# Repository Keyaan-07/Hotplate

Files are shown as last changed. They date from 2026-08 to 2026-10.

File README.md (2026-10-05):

# Hotplate
An open-source hotplate designed to take power from USB type-C and then be configured and controlled over Wi-Fi. It uses the ESP32-C3 microcontroller, along with 16MB of storage. There are two terminal blocks to connect with the heating element and it's temperature sensor. There is short circuit protection along with accurate current measurement on the power lines. The control frequency is 10KHz for the heating element. The heating element can be mounted on standoffs so as to not heat the surface below it. 

Check out the Project's files on KiCanvas([PCB](https://github.com/Keyaan-07/Hotplate/tree/main/hardware) and [Heating element](https://github.com/Keyaan-07/Hotplate/tree/main/hardware)) and [Onshape](https://cad.onshape.com/documents/19aaa7739f645838b4ad0ae7/w/c026fb920f31f6c5ff4ae7d0/e/9c380aaf866f8abdd3d2d5e3)!

Features:  
- Upto 45W heating
- Wi-Fi Controlled
- Overcurrent protection & shortcircuit protection. 
- accurate current measurement
- Integrated temperature sensor
- Open Source!
- integrated ADC for NTC temperature readings
  
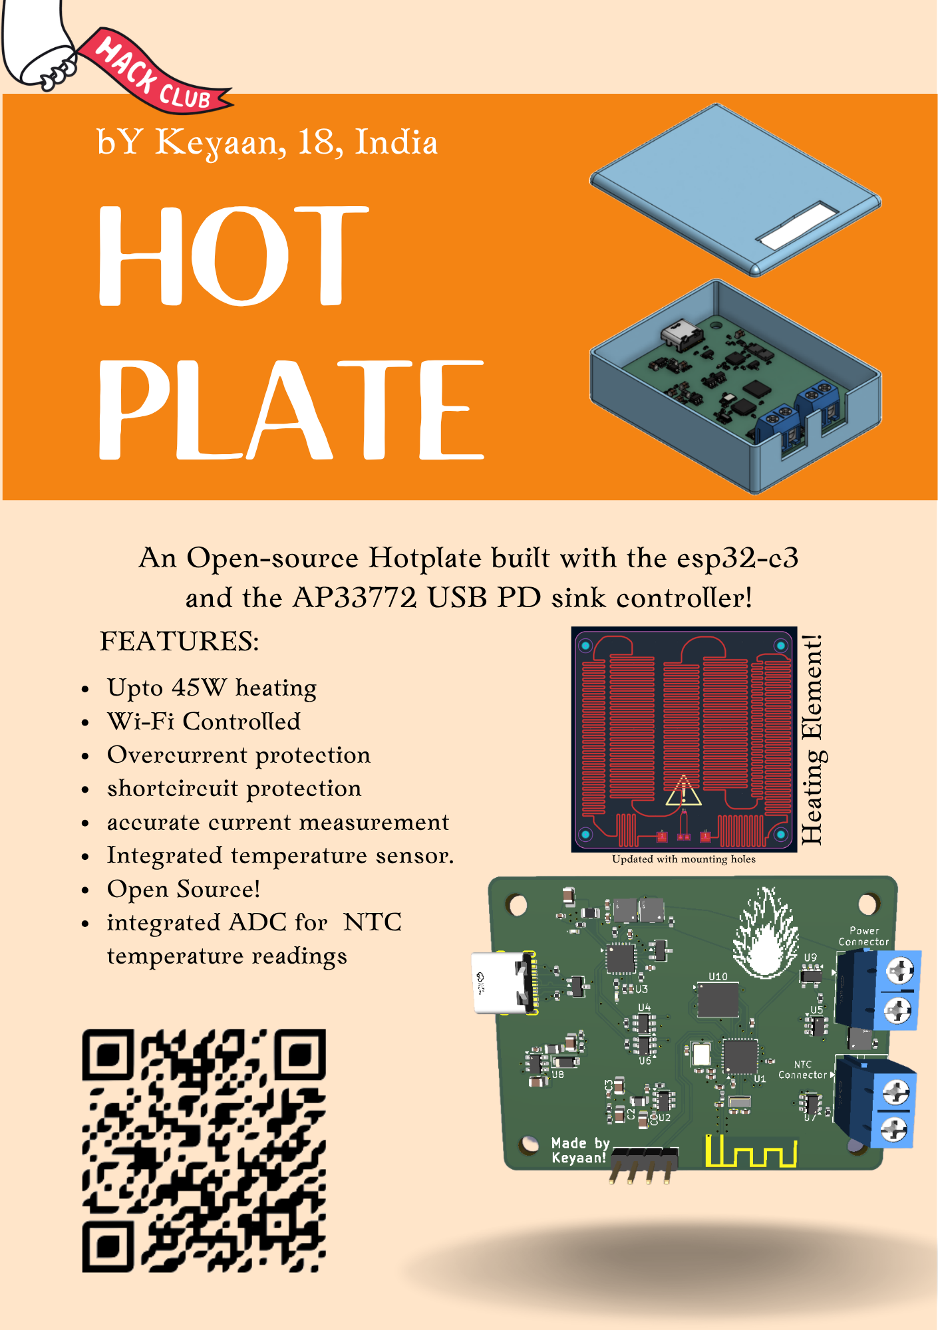
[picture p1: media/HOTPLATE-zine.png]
zine

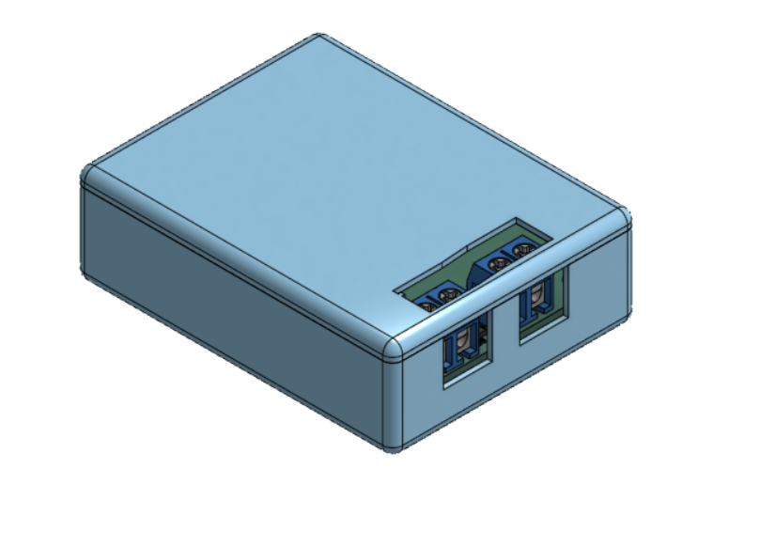
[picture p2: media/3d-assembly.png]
enclosure
  
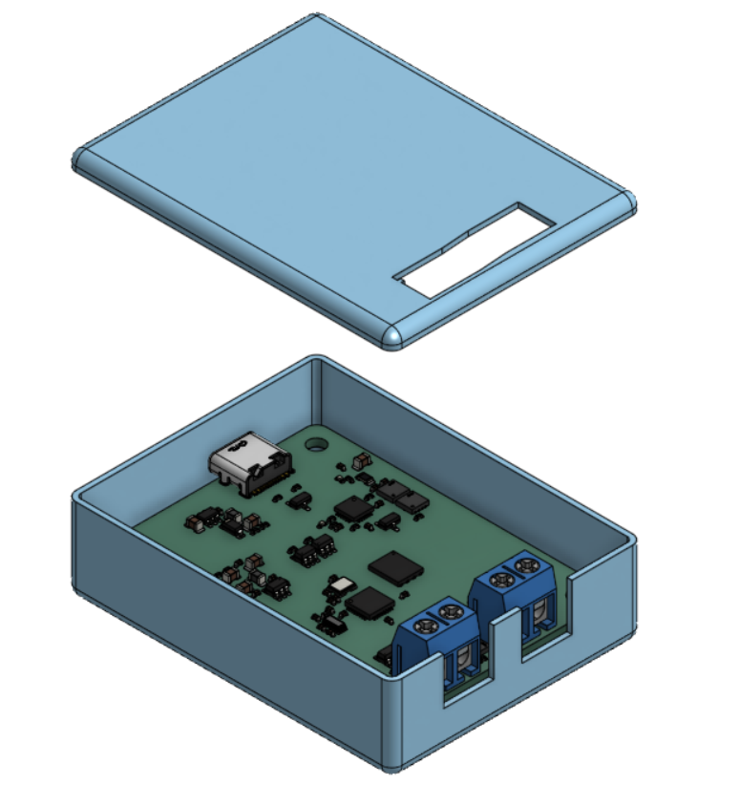
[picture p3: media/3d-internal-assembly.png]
internal parts
  
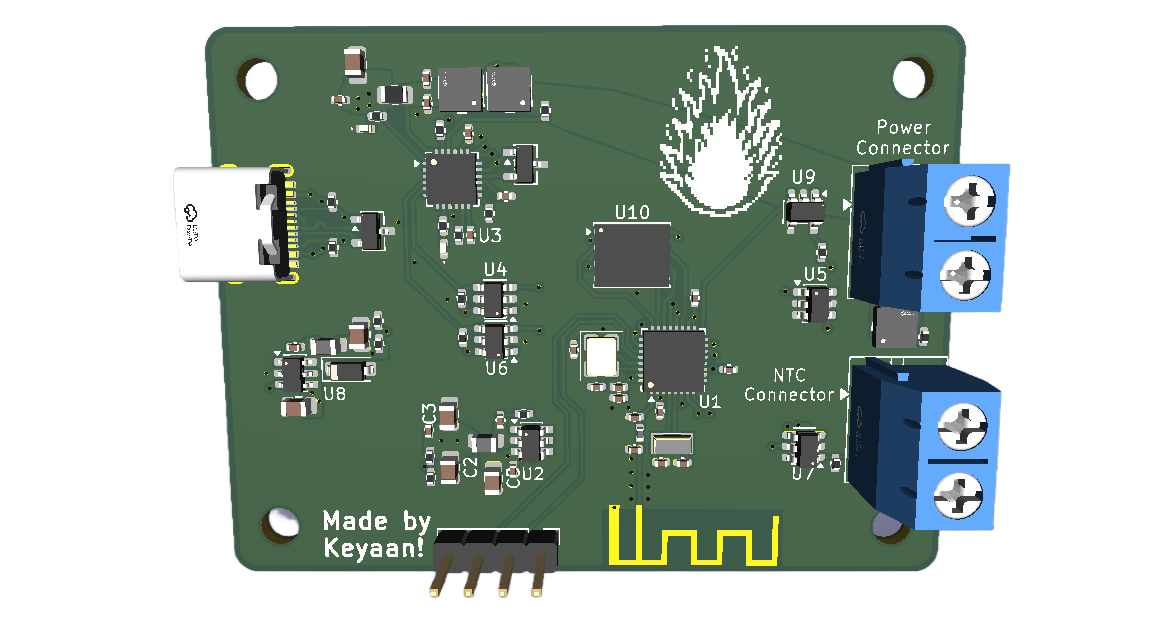
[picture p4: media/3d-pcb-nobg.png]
3d-pcb
  
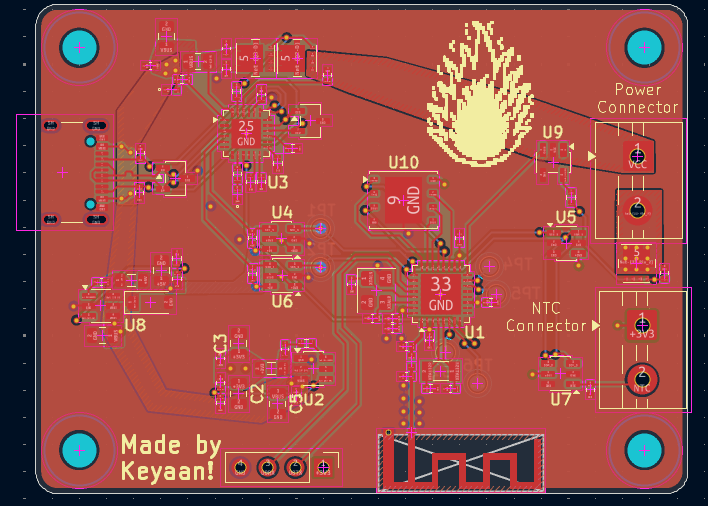
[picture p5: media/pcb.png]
pcb
  
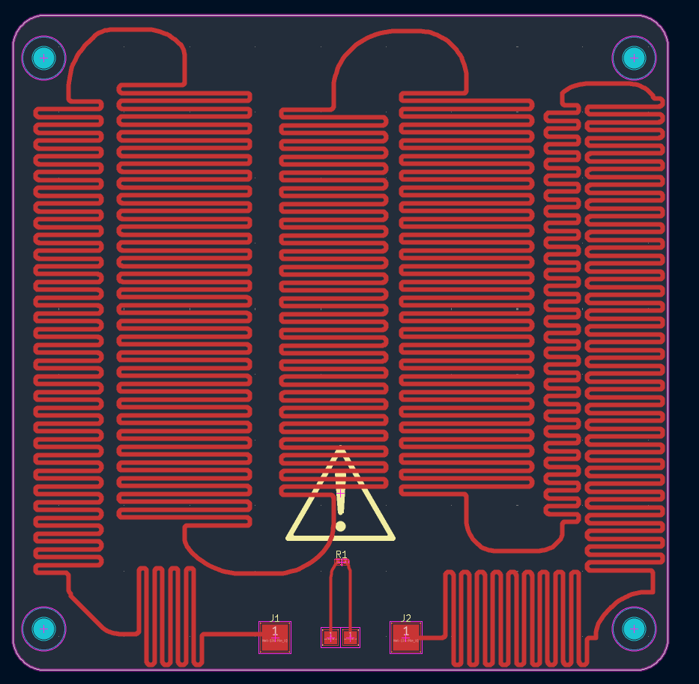
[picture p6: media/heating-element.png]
heating element
  
schematic  

wiring diagram between two parts:   
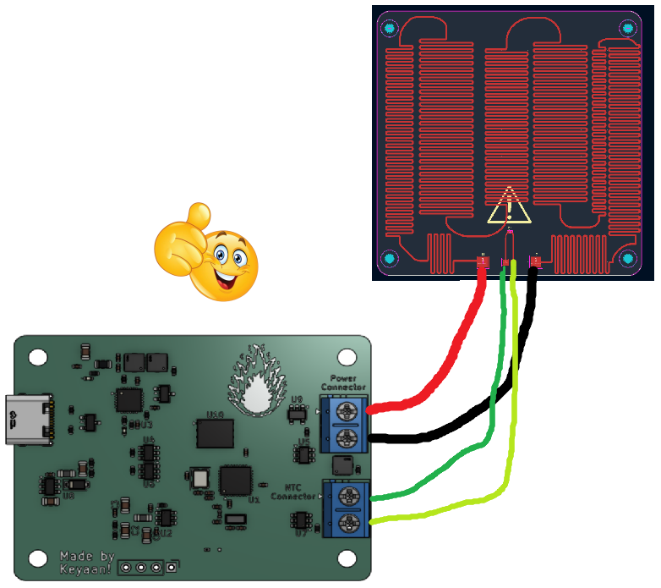
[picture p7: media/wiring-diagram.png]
wiring diagram
  
##### (made by yours truly in paint)

### Why i made this project
I really wanted to build a custom hotplate so that i could make my own PCBs with ease and not struggle!
The heating element is made up of an aluminium PCB so that there is good thermal conductivity.

### Assembly instructions
1. Upload the gerber files from the [production](/hardware/production/) folder to your specific PCB fab. 
2. Order PCBs and a stencil for soldering. 
3. Order all the parts from the links in the [bom.csv](/bom.csv) file. 
4. Get some solder paste and paste it onto the PCB. pick and place all the components. 
5. heat the PCB in an oven/a reflow station. 
6. connect all the THT components
7. flash the firmware via a USB to UART converter. 
8. connect the heating element. You are done!

### Note about firmware
I dont think i will be able to do the firmware unless and until i have the project in hand, because this requires proper PID tuning to just get the temperature right, and also it needs to be adjusted for errors in temperature measurement and power control!

# BOM
|Sr. No.|Designator |Function |Value |Footprint |Quantity|Price |Amount |Link |
|---|---|---|---|---|---|---|---|---|
|1 |PCB+Stencil |PCB+Stencil |PCB+Stencil |PCB+Stencil |5+1 |7+3.07 |10.07  |https://jlcpcb.com/ |
|2 |Aluminium PCB |Heating element | | |5 |0.8 |4 |https://jlcpcb.com/ |
|2 |C1, C14, C15, C16, C17, C20, C21, C22, C23, C4, C6, C7|capacitors |100n |402 |100 |0.0064 |0.64 |https://www.lcsc.com/product-detail/C100072.html  |
|3 |C10, C11, C8, C9 |capacitors |15p |402 |100 |0.0102 |1.02 |https://www.lcsc.com/product-detail/C326803.html  |
|4 |C12 |capacitors |1.8p |402 |100 |0.0081 |0.81 |https://www.lcsc.com/product-detail/C327209.html  |
|5 |C13 |capacitors |1.2p |402 |100 |0.0055 |0.55 |https://www.lcsc.com/product-detail/C327292.html  |
|6 |C18, C19, C24 |capacitors |1u |402 |50 |0.0162 |0.81 |https://www.lcsc.com/product-detail/C52923.html |
|7 |C2, C25, C26, C27, C3, C5 |capacitors |10u |805 |20 |0.1007 |2.014  |https://www.lcsc.com/product-detail/C15850.html |
|8 |D1, D2 |LED |LED |402 |50 |0.0084 |0.42 |https://www.lcsc.com/product-detail/C25503345.html|
|9 |D3, D4 |ESD protection diodes|ESDA5V3L |SOT-23-3 |5 |0.1017 |0.5085 |https://www.lcsc.com/product-detail/C87911.html |
|10 |D5 |buck diode |1N4148W |D_SOD-123 |50 |0.0084 |0.42 |https://www.lcsc.com/product-detail/C917030.html  |
|11 |J1 |USB connector |USB_C_Receptacle_USB2.0_16P|USB_C_Receptacle_XKB_U262-16XN-4BVC11 |10 |0.062 |0.62 |https://www.lcsc.com/product-detail/C393939.html  |
|12 |J2, J3 |Screw terminals |Screw_Terminal_01x02 |TerminalBlock_MaiXu_MX126-5.0-02P_1x02_P5.00mm|5 |0.102 |0.51 |https://www.lcsc.com/product-detail/C474881.html  |
|13 |J4 | |Conn_01x04_Pin |PinHeader_1x04_P2.54mm_Vertical |5 |0.0319 |0.1595 |https://www.lcsc.com/product-detail/C32713270.html|
|14 |L1, L2 | |4.7u |805 |5 |0.1004 |0.502  |https://www.lcsc.com/product-detail/C17701166.html|
|15 |L3 | |3n |402 |20 |0.0042 |0.084  |https://www.lcsc.com/product-detail/C142230.html  |
|16 |Q1, Q2, Q3 | |AON7262E |DFN-5-1EP_3x3mm_P0.65mm_AON7262E |3 |0.65 |1.95 |https://www.lcsc.com/product-detail/C176755.html  |
|17 |R1 | |30 |402 |100 |0.0006 |0.06 |https://www.lcsc.com/product-detail/C54920779.html|
|18 |R10, R14, R15, R9 | |5.1k |402 |100 |0.0054 |0.54 |https://www.lcsc.com/product-detail/C105872.html  |
|19 |R11 | |1k |402 |100 |0.0041 |0.41 |https://www.lcsc.com/product-detail/C106235.html  |
|20 |R12, R13 | |100k |402 |100 |0.0044 |0.44 |https://www.lcsc.com/product-detail/C60491.html |
|21 |R16, R18, R3, R6, TH1 | |10k |402 |100 |0.0038 |0.38 |https://www.lcsc.com/product-detail/C60490.html |
|22 |R17 | |31.6k |402 |100 |0.0021 |0.21 |https://www.lcsc.com/product-detail/C2998091.html |
|23 |R2 | |56k |402 |100 |0.0018 |0.18 |https://www.lcsc.com/product-detail/C2906875.html |
|24 |R4, R7, R8 | |100 |402 |100 |0.0044 |0.44 |https://www.lcsc.com/product-detail/C106232.html  |
|25 |R5 | |5m |805 |10 |0.0514 |0.514  |https://www.lcsc.com/product-detail/C22450690.html|
|26 |U1 | |ESP32-C3 |QFN-32-1EP_5x5mm_P0.5mm_EP3.7x3.7mm |1 |1.85 |1.85 |https://www.lcsc.com/product-detail/C2838500.html |
|27 |U10 | |W25Q128JVP |WSON-8-1EP_6x5mm_P1.27mm_EP3.4x4.3mm |1 |3.47 |3.47 |https://www.lcsc.com/product-detail/C190862.html  |
|28 |U2 | |TPS56339DDC |SOT-23-6 |1 |0.37 |0.37 |https://www.lcsc.com/product-detail/C2071106.html |
|29 |U3 | |AP33772SDKZ-xx-FA02 |QFN-24-1EP_4x4mm_P0.5mm_EP2.7x2.7mm |1 |2.69 |2.69 |https://www.lcsc.com/product-detail/C5244513.html |
|30 |U4, U6 | |TXS0101DBV |SOT-23-6 |2 |0.585 |1.17 |https://www.lcsc.com/product-detail/C132604.html  |
|31 |U5 | |TMP100 |SOT-23-6 |1 |1.02 |1.02 |https://www.lcsc.com/product-detail/C31810.html |
|32 |U7 | |ADS1110 |SOT-23-6 |1 |1.5 |1.5 |https://www.lcsc.com/product-detail/C16598.html |
|33 |U8 | |LM2842Y |TSOT-23-6 |5 |0.2226 |1.113  |https://www.lcsc.com/product-detail/C30170092.html|
|34 |U9 | |MCP1416 |SOT-23-5 |1 |0.52 |0.52 |https://www.lcsc.com/product-detail/C83775.html |
|35 |Y1 | |40MHz |Crystal_SMD_3225-4Pin_3.2x2.5mm |5 |0.0681 |0.3405 |https://www.lcsc.com/product-detail/C5261245.html |
|36 |Y2 | |32.786KHz |Crystal_SMD_3215-2Pin_3.2x1.5mm |5 |0.19 |0.95 |https://www.lcsc.com/product-detail/C46604081.html|
| | | | | | |Total |43.2555| |
| | | | | | |Parts shipping|11 | |
| | | | | | |JLC shipping  |16.7 | |
| | | | | | |total |70.9555| |

# License
Licensed under the MIT license.

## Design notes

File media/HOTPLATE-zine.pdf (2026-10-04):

# HOT

## bY Keyaan, 18, India

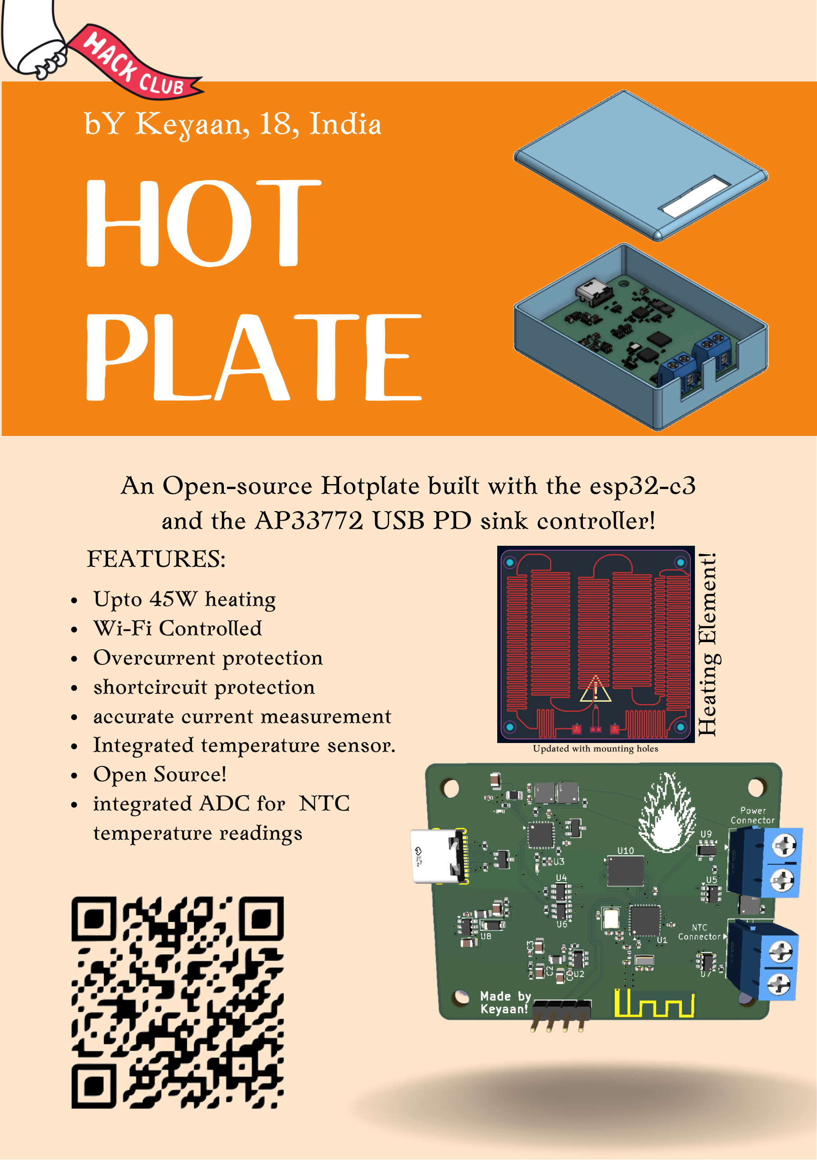
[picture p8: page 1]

# PLATE

### An Open-source Hotplate built with the esp32-c3 and the AP33772 USB PD sink controller!

Upto 45W heating
Wi-Fi Controlled
Overcurrent protection
shortcircuit protection
accurate current measurement Integrated temperature sensor. Open Source!
integrated ADC for NTC
temperature readings

FEATURES:

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
Updated with mounting holes

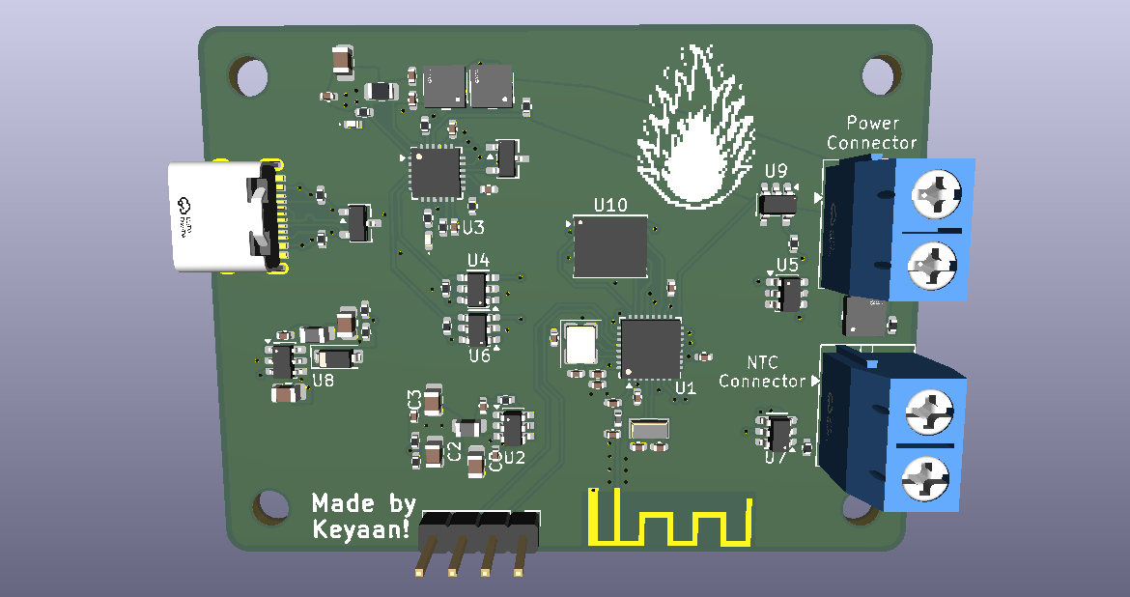
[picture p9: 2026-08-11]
media/3d-pcb.png

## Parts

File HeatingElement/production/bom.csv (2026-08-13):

Designator | Footprint | Quantity | Value | LCSC Part #
J1, J2 | TestPoint_Pad_4.0x4.0mm | 2 | Conn_01x01_Pin
J3, J4 | TestPoint_Pad_2.0x2.0mm | 2 | Conn_01x01_Pin
R1 | 0402 | 1 | NTC

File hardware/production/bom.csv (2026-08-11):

Designator | Footprint | Quantity | Value | LCSC Part #
AE1 | Texas_SWRA117D_2.4GHz_Left | 1 | Antenna_Shield
C1, C14, C15, C16, C17, C20, C21, C22, C23, C4, C6, C7 | 0402 | 12 | 100n
C10, C11, C8, C9 | 0402 | 4 | 15p
C12 | 0402 | 1 | 1.8p
C13 | 0402 | 1 | 1.2p
C18, C19, C24 | 0402 | 3 | 1u
C2, C25, C26, C27, C3, C5 | 0805 | 6 | 10u
D1, D2 | 0402 | 2 | LED
D3, D4 | SOT-23-3 | 2 | ESDA5V3L
D5 | D_SOD-123 | 1 | 1N4148W
J1 | USB_C_Receptacle_XKB_U262-16XN-4BVC11 | 1 | USB_C_Receptacle_USB2.0_16P
J2, J3 | TerminalBlock_MaiXu_MX126-5.0-02P_1x02_P5.00mm | 2 | Screw_Terminal_01x02
J4 | PinHeader_1x04_P2.54mm_Vertical | 1 | Conn_01x04_Pin
L1, L2 | 0805 | 2 | 4.7u
L3 | 0402 | 1 | 3n
Q1, Q2, Q3 | DFN-5-1EP_3x3mm_P0.65mm_AON7262E | 3 | AON7262E
R1 | 0402 | 1 | 30
R10, R14, R15, R9 | 0402 | 4 | 5.1k
R11 | 0402 | 1 | 1k
R12, R13 | 0402 | 2 | 100k
R16, R18, R3, R6, TH1 | 0402 | 5 | 10k
R17 | 0402 | 1 | 31.6k
R2 | 0402 | 1 | 56k
R4, R7, R8 | 0402 | 3 | 100
R5 | 0805 | 1 | 5m
TP1, TP2, TP3, TP4, TP5, TP6 | TestPoint_Pad_D1.5mm | 6 | TestPoint
U1 | QFN-32-1EP_5x5mm_P0.5mm_EP3.7x3.7mm | 1 | ESP32-C3
U10 | WSON-8-1EP_6x5mm_P1.27mm_EP3.4x4.3mm | 1 | W25Q128JVP
U2 | SOT-23-6 | 1 | TPS56339DDC
U3 | Texas_RTW_WQFN-24-1EP_4x4mm_P0.5mm_EP2.7x2.7mm | 1 | AP33772SDKZ-xx-FA02
U4, U6 | SOT-23-6 | 2 | TXS0101DBV
U5 | SOT-23-6 | 1 | TMP100
U7 | SOT-23-6 | 1 | ADS1110
U8 | TSOT-23-6 | 1 | LM2842Y
U9 | SOT-23-5 | 1 | MCP1416
Y1 | Crystal_SMD_3225-4Pin_3.2x2.5mm | 1 | 40MHz
Y2 | Crystal_SMD_3215-2Pin_3.2x1.5mm | 1 | 32.786KHz

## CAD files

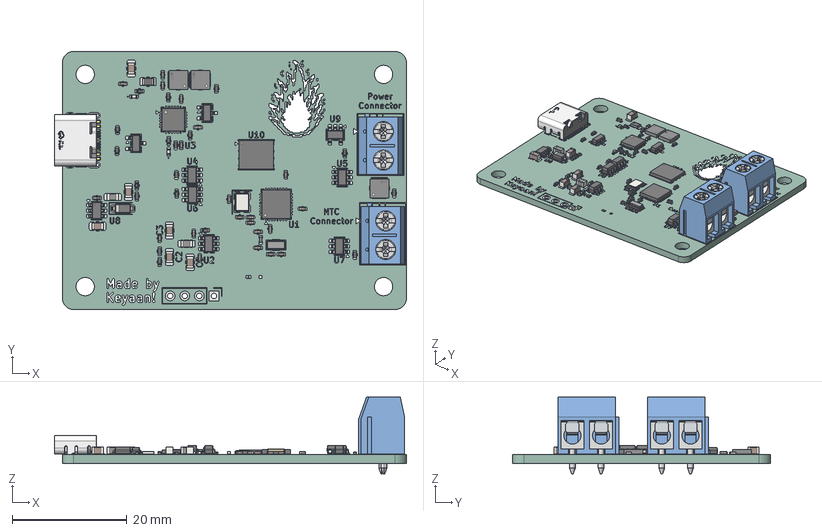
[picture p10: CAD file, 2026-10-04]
3d/hotplate controller.step
61.4 x 45.0 x 13.4 mm
C_0805_2012Metric x 6
C_0402_1005Metric x 21
LED_0402_1005Metric x 2
R_0402_1005Metric x 18
L_0805_2012Metric x 2
Crystal_SMD_3225-4Pin_3.2x2.5mm
DFN-8_L3.3-W3.3-P0.65-BL x 3
Texas_RTW_WQFN-24-1EP_4x4mm_P0.5mm_EP2.7x2.7mm
L_0402_1005Metric
QFN-32-1EP_5x5mm_P0.5mm_EP3.7x3.7mm
SOT-23-6 x 5
R_0805_2012Metric
SOT-23-3 x 2
Crystal_SMD_3215-2Pin_3.2x1.5mm
USB-C-SMD_TYPE-C16PIN
SOT-23-5
Download_STP_691102710002 (rev1) x 2
D_SOD-123
TSOT-23-6
WSON-8-1EP_6x5mm_P1.27mm_EP3.4x4.3mm
hot573D_pad
hot573D_silkscreen x 2
hot573D_PCB

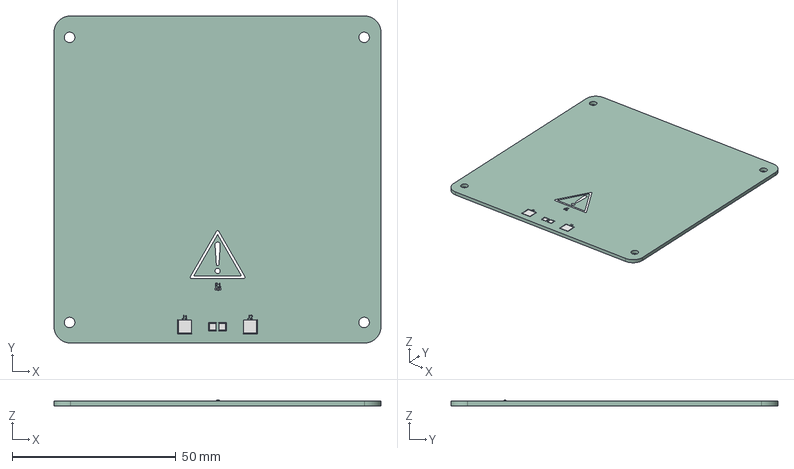
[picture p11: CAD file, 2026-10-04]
HeatingElement/HeatingElement.step
100.0 x 100.0 x 1.94 mm
R_0402_1005Metric
HeaFAF2_pad
HeaFAF2_silkscreen
HeaFAF2_PCB

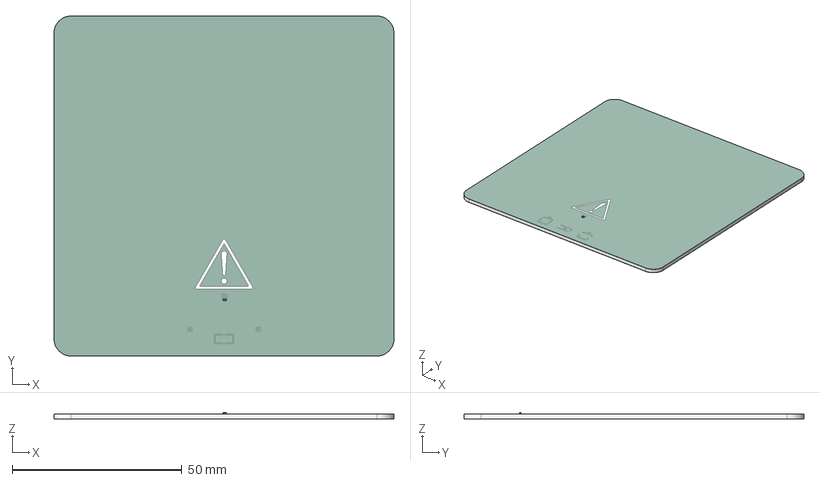
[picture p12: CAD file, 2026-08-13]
3d/heatingelement.step
100.0 x 100.0 x 1.99 mm
R_0402_1005Metric
HeatingElement_silkscreen
HeatingElement_soldermask x 2
HeatingElement_PCB

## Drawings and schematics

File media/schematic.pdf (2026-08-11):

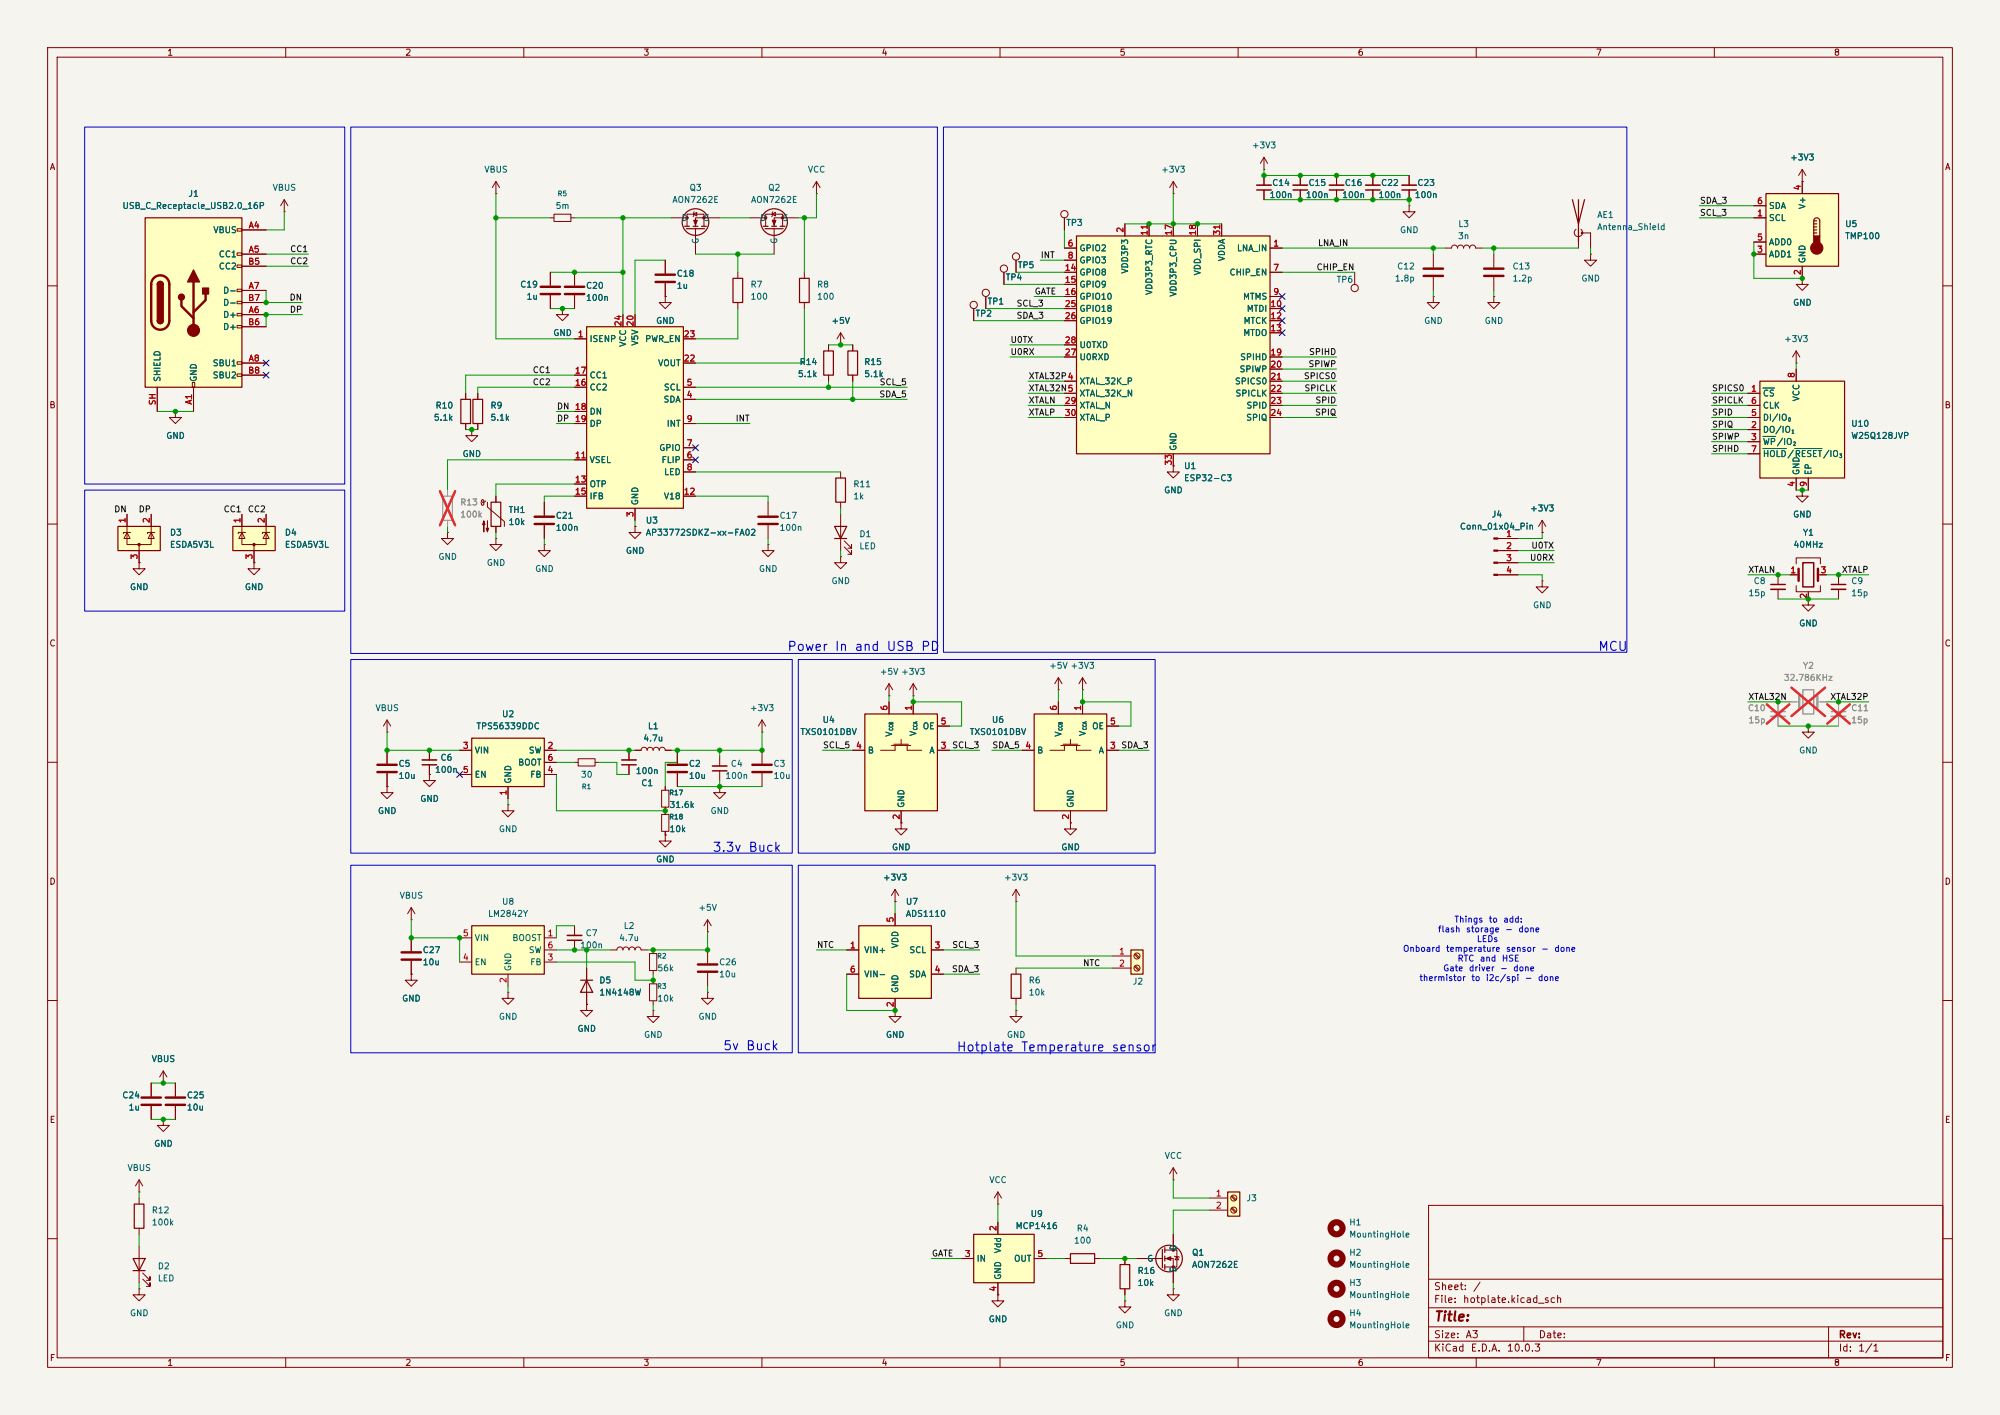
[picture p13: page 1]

thermistor to i2c/spi - done Power In and USB PD

Things to add: flash storage - done

LEDs Onboard temperature sensor - done RTC and HSE Gate driver - done

Size: A3 | Rev: | F Date:
KiCad E.D.A. 10.0.3 | Id: 1/1

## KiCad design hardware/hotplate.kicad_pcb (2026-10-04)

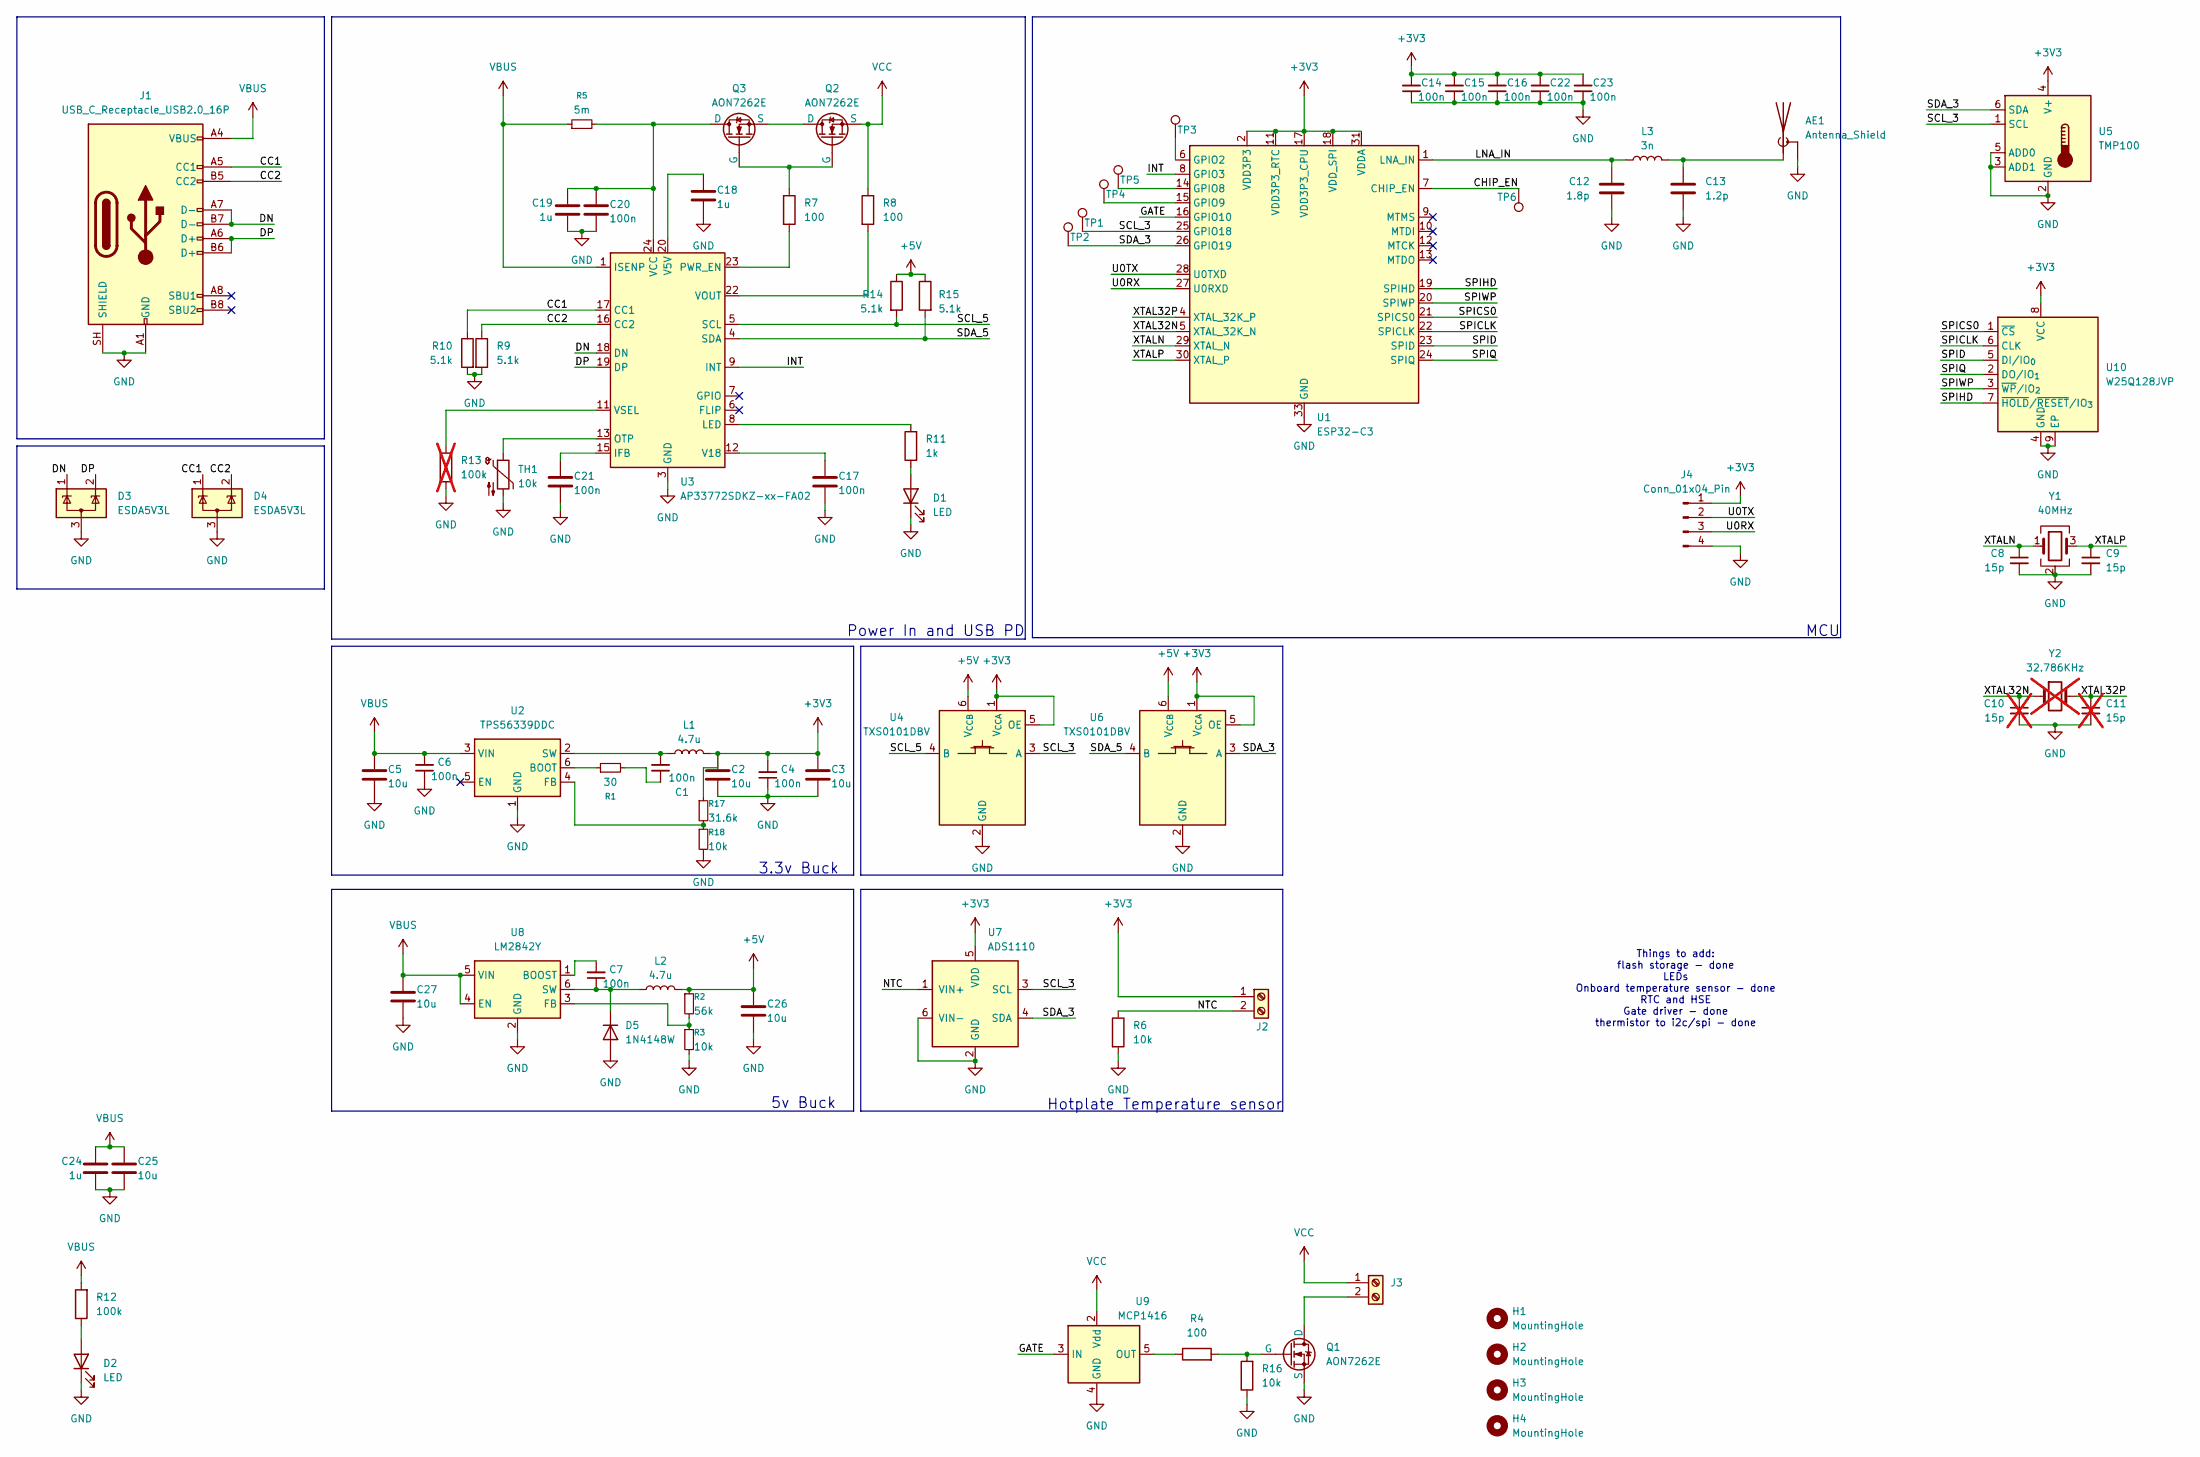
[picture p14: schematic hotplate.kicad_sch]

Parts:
AE1: Antenna_Shield; Texas_SWRA117D_2.4GHz_Left
C1, C4, C6, C7, C14, C15, C16, C17, C20, C21, C22, C23: 100n; C_0402_1005Metric
C2, C3, C5, C25, C26, C27: 10u; C_0805_2012Metric
C8, C9: 15p; C_0402_1005Metric
C10, C11: 15p; C_0402_1005Metric; not fitted
C12: 1.8p; C_0402_1005Metric
C13: 1.2p; C_0402_1005Metric
C18, C19, C24: 1u; C_0402_1005Metric
D1, D2: LED; LED_0402_1005Metric
D3, D4: ESDA5V3L; SOT-23-3
D5: 1N4148W; D_SOD-123
H1, H2, H3, H4: MountingHole; MountingHole_3.2mm_M3
J1: USB_C_Receptacle_USB2.0_16P; USB_C_Receptacle_XKB_U262-16XN-4BVC11
J2, J3: Screw_Terminal_01x02; TerminalBlock_MaiXu_MX126-5.0-02P_1x02_P5.00mm
J4: Conn_01x04_Pin; PinHeader_1x04_P2.54mm_Vertical
L1, L2: 4.7u; L_0805_2012Metric
L3: 3n; L_0402_1005Metric
Q1, Q2, Q3: AON7262E; DFN-5-1EP_3x3mm_P0.65mm_AON7262E
R1: 30; R_0402_1005Metric
R2: 56k; R_0402_1005Metric
R3, R6, R16, R18: 10k; R_0402_1005Metric
R4, R7, R8: 100; R_0402_1005Metric
R5: 5m; R_0805_2012Metric
R9, R10, R14, R15: 5.1k; R_0402_1005Metric
R11: 1k; R_0402_1005Metric
R12: 100k; R_0402_1005Metric
R13: 100k; R_0402_1005Metric; not fitted
R17: 31.6k; R_0402_1005Metric
TH1: 10k; R_0402_1005Metric
TP1, TP2, TP3, TP4, TP5, TP6: TestPoint; TestPoint_Pad_D1.5mm
U1: ESP32-C3; QFN-32-1EP_5x5mm_P0.5mm_EP3.7x3.7mm
U2: TPS56339DDC; SOT-23-6
U3: AP33772SDKZ-xx-FA02; Texas_RTW_WQFN-24-1EP_4x4mm_P0.5mm_EP2.7x2.7mm
U4, U6: TXS0101DBV; SOT-23-6
U5: TMP100; SOT-23-6
U7: ADS1110; SOT-23-6
U8: LM2842Y; TSOT-23-6
U9: MCP1416; SOT-23-5
U10: W25Q128JVP; WSON-8-1EP_6x5mm_P1.27mm_EP3.4x4.3mm
Y1: 40MHz; Crystal_SMD_3225-4Pin_3.2x2.5mm
Y2: 32.786KHz; Crystal_SMD_3215-2Pin_3.2x1.5mm; not fitted

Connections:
+3V3: C2.1, C3.1, C4.2, C14.2, C15.2, C16.2, C22.2, C23.2, J2.1, J4.1, L1.2, R17.1, U1.2 (VDD3P3), U1.3 (VDD3P3), U1.11 (VDD3P3_RTC), U1.17 (VDD3P3_CPU), U1.18 (VDD_SPI), U1.31 (VDDA), U1.32 (VDDA), U4.1 (V_{CCA}), U4.5 (OE), U5.4 (V+), U6.1 (V_{CCA}), U6.5 (OE), U7.5 (VDD), U10.8 (VCC)
+5V: C26.1, L2.2, R2.1, R14.1, R15.1, U4.6 (V_{CCB}), U6.6 (V_{CCB})
/CC1: D4.1 (K), J1.A5 (CC1), R10.1, U3.17 (CC1)
/CC2: D4.2 (K), J1.B5 (CC2), R9.1, U3.16 (CC2)
/CHIP_EN: TP6.1 (1_1), U1.7 (CHIP_EN)
/DN: D3.1 (K), J1.A7 (D-), J1.B7 (D-), U3.18 (DN)
/DP: D3.2 (K), J1.A6 (D+), J1.B6 (D+), U3.19 (DP)
/GATE: U1.16 (GPIO10), U9.3 (IN)
/INT: U1.8 (GPIO3), U3.9 (INT)
/LNA_IN: C12.1, L3.1, U1.1 (LNA_IN)
/NTC: J2.2, R6.1, U7.1 (VIN+)
/SCL_3: TP1.1 (1_1), U1.25 (GPIO18), U4.3 (A), U5.1 (SCL), U7.3 (SCL)
/SCL_5: R14.2, U3.5 (SCL), U4.4 (B)
/SDA_3: TP2.1 (1_1), U1.26 (GPIO19), U5.6 (SDA), U6.3 (A), U7.4 (SDA)
/SDA_5: R15.2, U3.4 (SDA), U6.4 (B)
/SPICLK: U1.22 (SPICLK), U10.6 (CLK)
/SPICS0: U1.21 (SPICS0), U10.1 (~CS)
/SPID: U1.23 (SPID), U10.5 (DI/IO_{0})
/SPIHD: U1.19 (SPIHD), U10.7 (~HOLD/~RESET/IO_{3})
/SPIQ: U1.24 (SPIQ), U10.2 (DO/IO_{1})
/SPIWP: U1.20 (SPIWP), U10.3 (~WP/IO_{2})
/U0RX: J4.3, U1.27 (U0RXD)
/U0TX: J4.2, U1.28 (U0TXD)
/XTAL32N: C10.1, U1.5 (XTAL_32K_N), Y2.1
/XTAL32P: C11.1, U1.4 (XTAL_32K_P), Y2.2
/XTALN: C8.1, U1.29 (XTAL_N), Y1.1
/XTALP: C9.1, U1.30 (XTAL_P), Y1.3
GND: AE1.2 (Shield), C2.2, C3.2, C4.1, C5.2, C6.1, C8.2, C9.2, C10.2, C11.2, C12.2, C13.2, C14.1, C15.1, C16.1, C17.2, C18.2, C19.2, C20.2, C21.2, C22.1, C23.1, C24.2, C25.2, C26.2, C27.2, D1.1 (K), D2.1 (K), D3.3 (A), D4.3 (A), D5.2 (A), J1.A1 (GND), J1.A12 (GND), J1.B1 (GND), J1.B12 (GND), J1.SH (SHIELD), J4.4, Q1.1 (S), Q1.2 (S), Q1.3 (S), R3.2, R6.2, R9.2, R10.2, R13.2, R16.1, R18.2, TH1.2, U1.33 (GND), U2.1 (GND), U3.3 (GND), U3.25 (GND), U4.2 (GND), U5.2 (GND), U5.3 (ADD1), U5.5 (ADD0), U6.2 (GND), U7.2 (GND), U7.6 (VIN-), U8.2 (GND), U9.4 (GND), U10.4 (GND), U10.9 (EP), Y1.2 (G), Y1.4 (G)
unnamed: AE1.1 (A), C13.1, L3.2
unnamed: C1.1, R1.2
unnamed: D1.2 (A), R11.1
unnamed: D2.2 (A), R12.1
unnamed: C7.1, D5.1 (K), L2.1, U8.6 (SW)
unnamed: J3.2, Q1.5 (D)
unnamed: Q1.4 (G), R4.2, R16.2
unnamed: Q2.5 (D), Q3.1 (S), Q3.2 (S), Q3.3 (S)
unnamed: Q2.4 (G), Q3.4 (G), R7.1
unnamed: C19.1, C20.1, Q3.5 (D), R5.2, U3.24 (VCC)
unnamed: TP3.1 (1_1), U1.6 (GPIO2)
unnamed: TP5.1 (1_1), U1.14 (GPIO8)
unnamed: TP4.1 (1_1), U1.15 (GPIO9)
unnamed: R1.1, U2.6 (BOOT)
unnamed: R17.2, R18.1, U2.4 (FB)
unnamed: C1.2, L1.1, U2.2 (SW)
unnamed: C21.1, U3.15 (IFB)
unnamed: R11.2, U3.8 (LED)
unnamed: TH1.1, U3.13 (OTP)
unnamed: R7.2, U3.23 (PWR_EN)
unnamed: C18.1, U3.20 (V5V)
unnamed: C17.1, U3.12 (V18)
unnamed: R8.2, U3.22 (VOUT)
unnamed: R13.1, U3.11 (VSEL)
unnamed: C7.2, U8.1 (BOOST)
unnamed: R2.2, R3.1, U8.3 (FB)
unnamed: R4.1, U9.5 (OUT)
VBUS: C5.1, C6.2, C24.1, C25.1, C27.1, J1.A4 (VBUS), J1.A9 (VBUS), J1.B4 (VBUS), J1.B9 (VBUS), R5.1, R12.2, U2.3 (VIN), U3.1 (ISENP), U8.4 (EN), U8.5 (VIN)
VCC: J3.1, Q2.1 (S), Q2.2 (S), Q2.3 (S), R8.1, U9.2 (Vdd)

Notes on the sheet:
3.3v Buck
5v Buck
Things to add: flash storage - done LEDs Onboard temperature sensor - done RTC and HSE Gate driver - done thermistor to i2c/spi - done
Power In and USB PD
Hotplate Temperature sensor
MCU

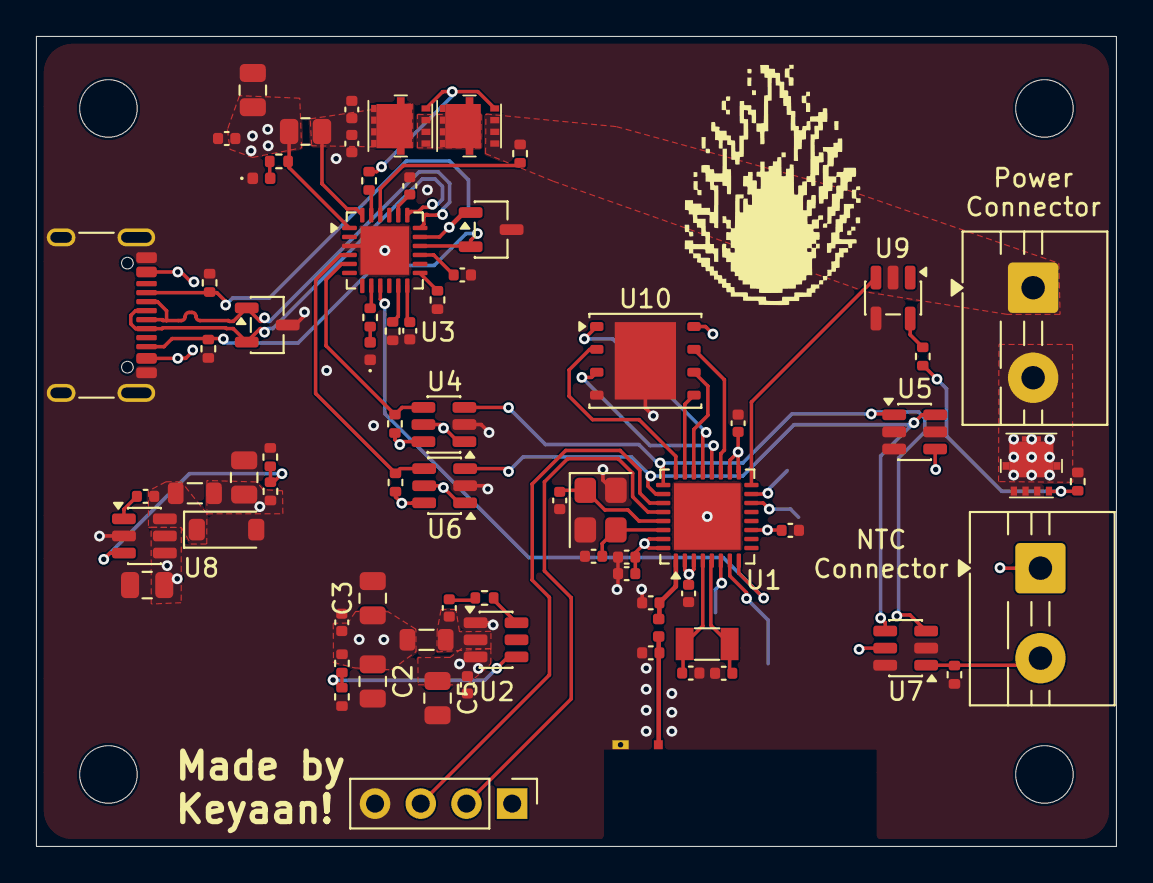
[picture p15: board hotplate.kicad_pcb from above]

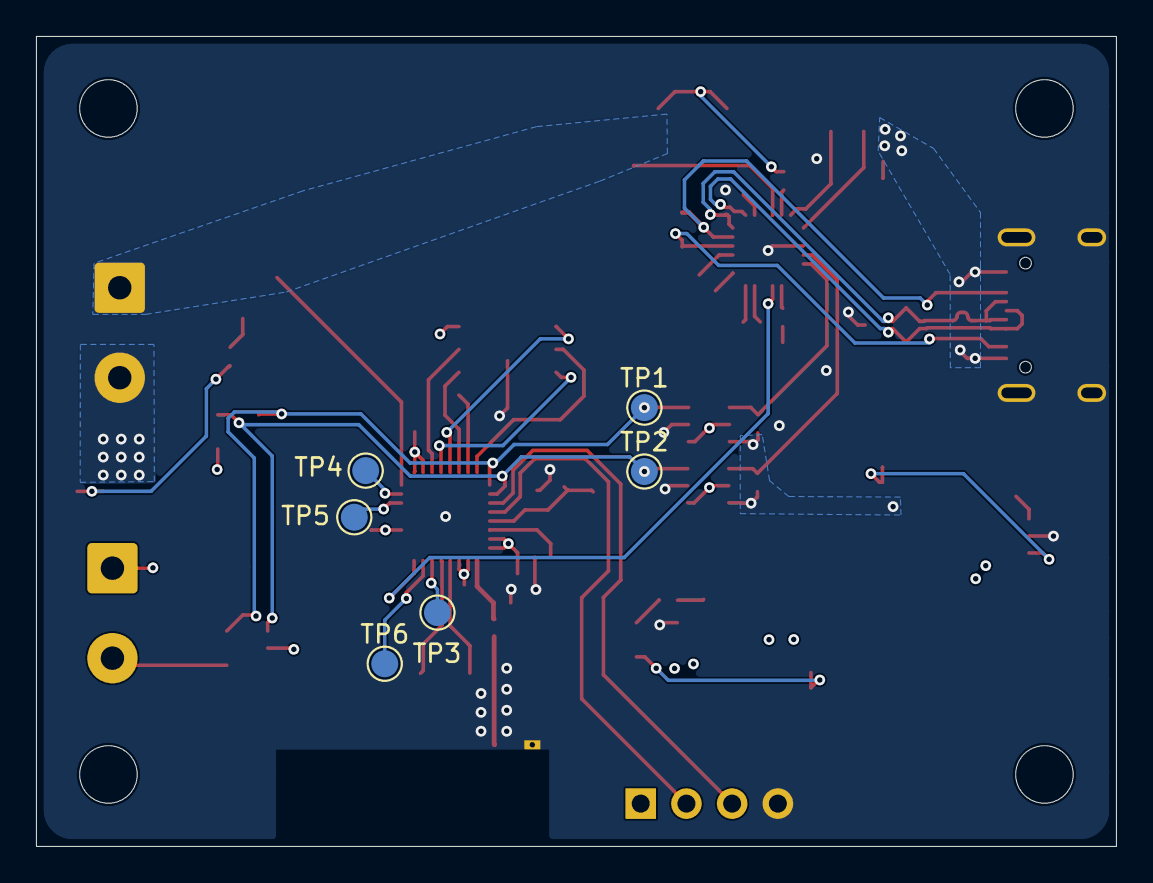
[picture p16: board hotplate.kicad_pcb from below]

Board: 4 copper layers, 60.0 x 45.0 mm, 84 parts (6 on the bottom side), 57 nets.

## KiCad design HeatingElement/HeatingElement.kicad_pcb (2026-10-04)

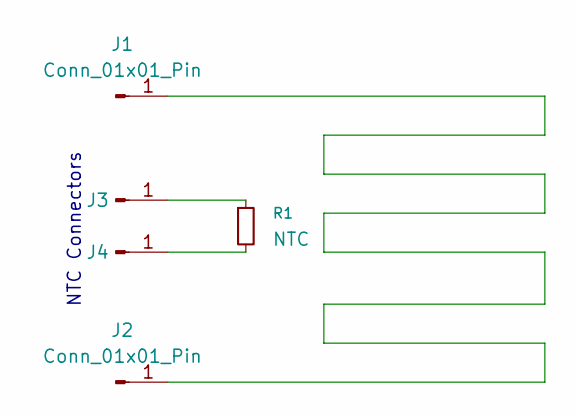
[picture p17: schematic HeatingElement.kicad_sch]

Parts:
J1, J2: Conn_01x01_Pin; TestPoint_Pad_4.0x4.0mm
J3, J4: Conn_01x01_Pin; TestPoint_Pad_2.0x2.0mm
R1: NTC; R_0402_1005Metric_Pad0.72x0.64mm_HandSolder

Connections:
unnamed: J1.1 (Pin_1_1), J2.1 (Pin_1_1)
unnamed: J3.1 (Pin_1_1), R1.1
unnamed: J4.1 (Pin_1_1), R1.2

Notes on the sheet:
NTC Connectors

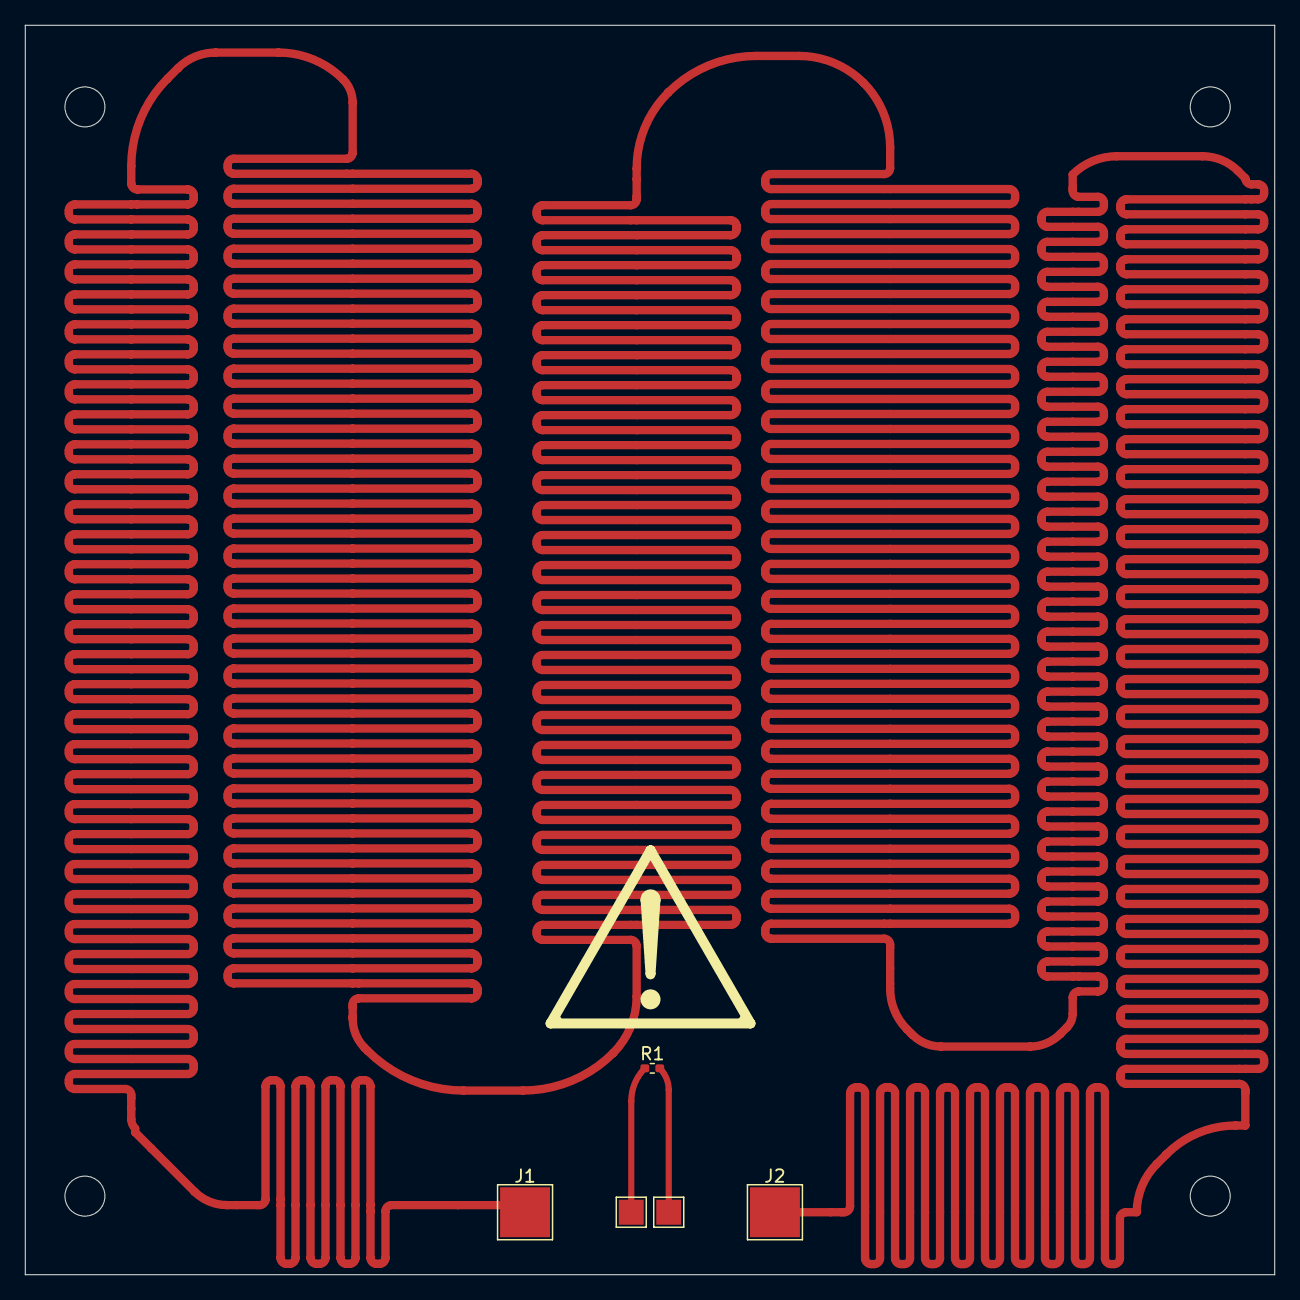
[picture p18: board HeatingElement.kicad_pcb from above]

Board: 2 copper layers, 100.0 x 100.0 mm, 5 parts (0 on the bottom side), 3 nets.

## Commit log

2026-06-15 Hello World
    [hotplate.kicad_pcb, hotplate.kicad_sch]
2026-06-17 schematic complete(almost)
    [hotplate.kicad_pcb, hotplate.kicad_sch]
2026-06-28 hotplate PCB
    [hotplate.kicad_pcb, hotplate.kicad_sch]
2026-06-28 AON7262 footprint
2026-06-28 schematic complete
    [hotplate.kicad_pcb, hotplate.kicad_sch]
2026-07-30 new pcb design
    [hotplate.kicad_pcb, hotplate.kicad_sch]
2026-08-10 PCB completed
    [hotplate.kicad_pcb, hotplate.kicad_sch]
2026-08-11 added production files
    [bom.csv, designators.csv, hotplate.kicad_pcb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]
2026-08-13 production files
    [designators.csv, hotplate.kicad_pcb]
2026-08-13 heating element made
    [HeatingElement.kicad_pcb, HeatingElement.kicad_sch, bom.csv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]
2026-08-13 added bom
    [bom.csv]
2026-08-13 added 3d files
    [heatingelement.step]
2026-10-04 added enclosure
    [HeatingElement.kicad_pcb, HeatingElement.step, hotplate controller.step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]
